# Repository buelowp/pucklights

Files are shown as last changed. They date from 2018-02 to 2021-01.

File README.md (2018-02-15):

# Remote Control Wireless Energizer Puck Lights

There are a new breed of low power LED puck lights available which make use of 433 Mhz radios 
for remote control. However, they currently do not integrate with any sort of Micro allowing 
for more accesible remote control.

This project connects to the provided remote and adds the ability to put a motion detector 
into the system which will turn the lights on or off based on movement and available ambient 
light. The idea is to use the puck lights remotely without having to run power for stair lights 
while achieving a viable benefit.

## What these are
https://www.lowes.com/pd/Energizer-Remote-Controlled-2-Pack-3-in-Battery-Puck-Light/1000268307

## The Plan
Basically, these are battery operated with a 433Mhz receiver, and a 12V remote that has two 
buttons, on and off. By powering the remote with a 12V source, and then regulating the power 
down to 5V for the micro, you can simply run two leads from NPN transistors to the two buttons 
to act as remote triggers. Add in a IR motion detector and a photocell, and you can remotely
trigger the lights on activity. Add in a micro that can easily receive events from the internet
and you can even turn the lights on or off from anywhere.

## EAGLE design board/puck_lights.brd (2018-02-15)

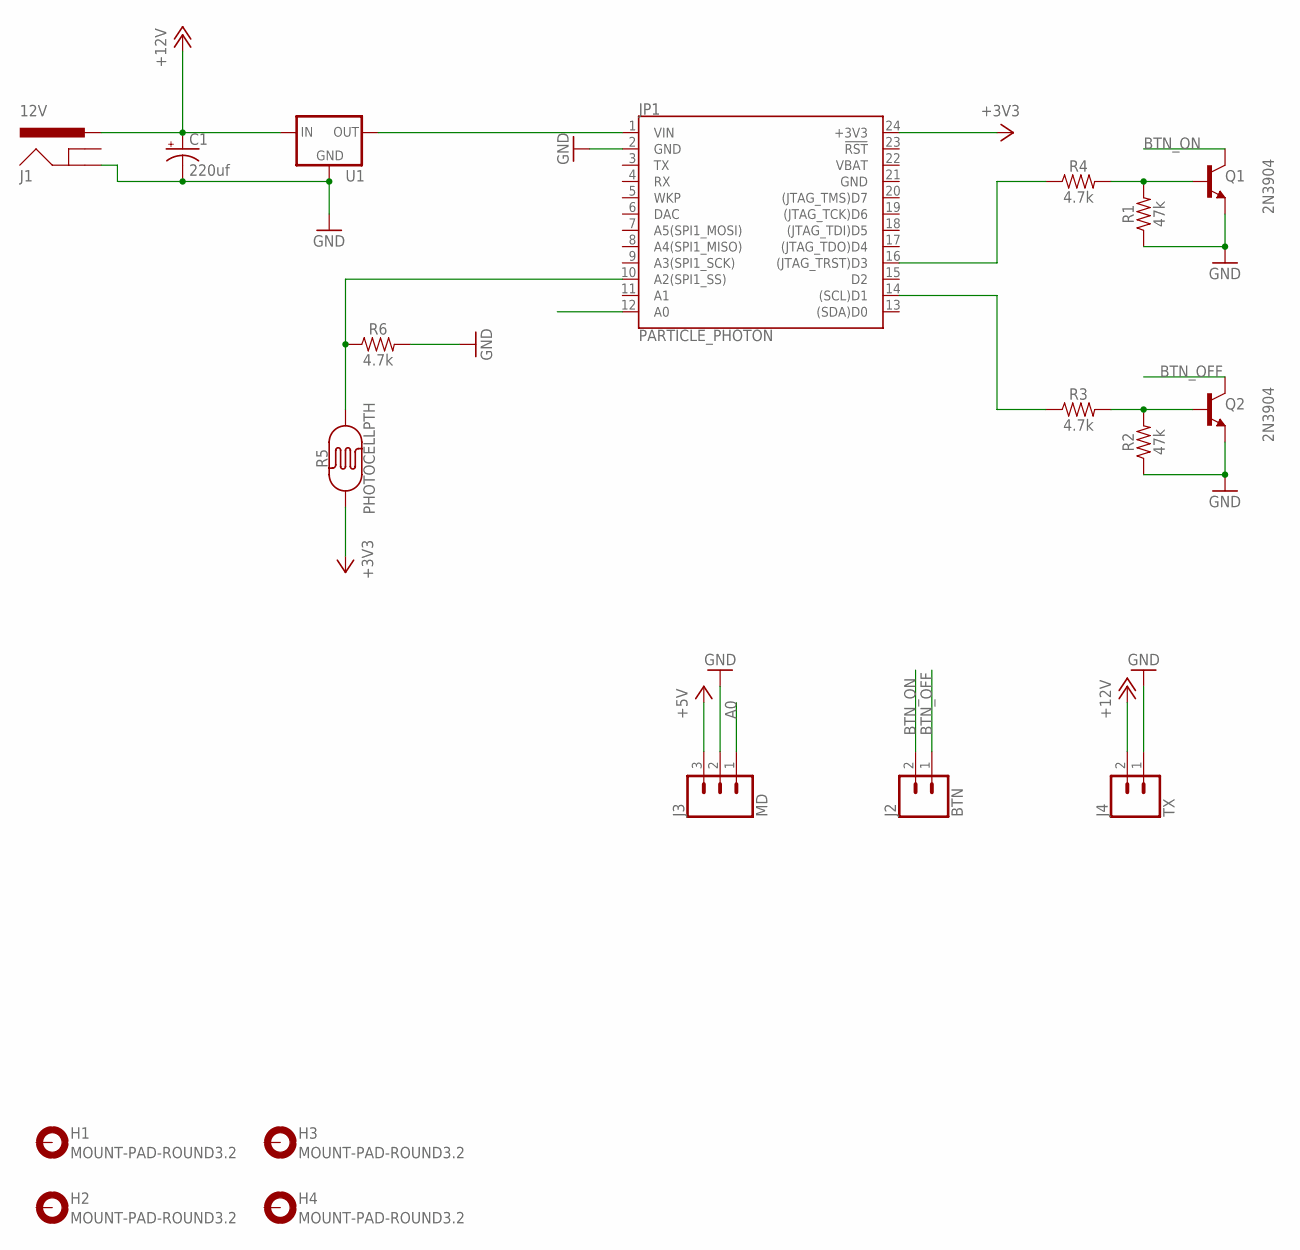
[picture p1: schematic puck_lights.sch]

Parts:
C1: 220uf; CPOL-RADIAL-2.5MM-6.5MM
H1, H2, H3, H4: MOUNT-PAD-ROUND3.2; 3,2-PAD
J1: 12V; POWER_JACK_SMD
J2: BTN; 1X02
J3: MD; JST-3-PTH
J4: TX; 1X02
JP1: PARTICLE_PHOTON
Q1, Q2: 2N3904; TO92
R1, R2: 47k; AXIAL-0.3
R3, R4, R6: 4.7k; AXIAL-0.3
R5: PHOTOCELLPTH; PHOTOCELL
U1: V_REG_78XX-TO-220; TO-220-ALT

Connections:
+3V3: JP1.24 (+3V3), R5.1
+5V: J3.3
+12V: C1.1 (+), J1.VIN0 (PWR), J4.2, U1.IN
A0: J3.1, JP1.12 (A0)
BTN_OFF: J2.1, Q2.1 (C)
BTN_ON: J2.2, Q1.1 (C)
GND: C1.2 (-), J1.P$4 (GND), J3.2, J4.1, JP1.2 (GND), JP1.21 (GND), Q1.3 (E), Q2.3 (E), R1.P$1 (1), R2.P$1 (1), R6.P$2 (2), U1.GND
unnamed: JP1.14 ((SCL)D1), R3.P$1 (1)
unnamed: JP1.1 (VIN), U1.OUT
unnamed: JP1.16 ((JTAG_TRST)D3), R4.P$1 (1)
unnamed: Q2.2 (B), R2.P$2 (2), R3.P$2 (2)
unnamed: Q1.2 (B), R1.P$2 (2), R4.P$2 (2)
unnamed: JP1.10 (A2(SPI1_SS)), R5.2, R6.P$1 (1)
VBAT: JP1.22 (VBAT)

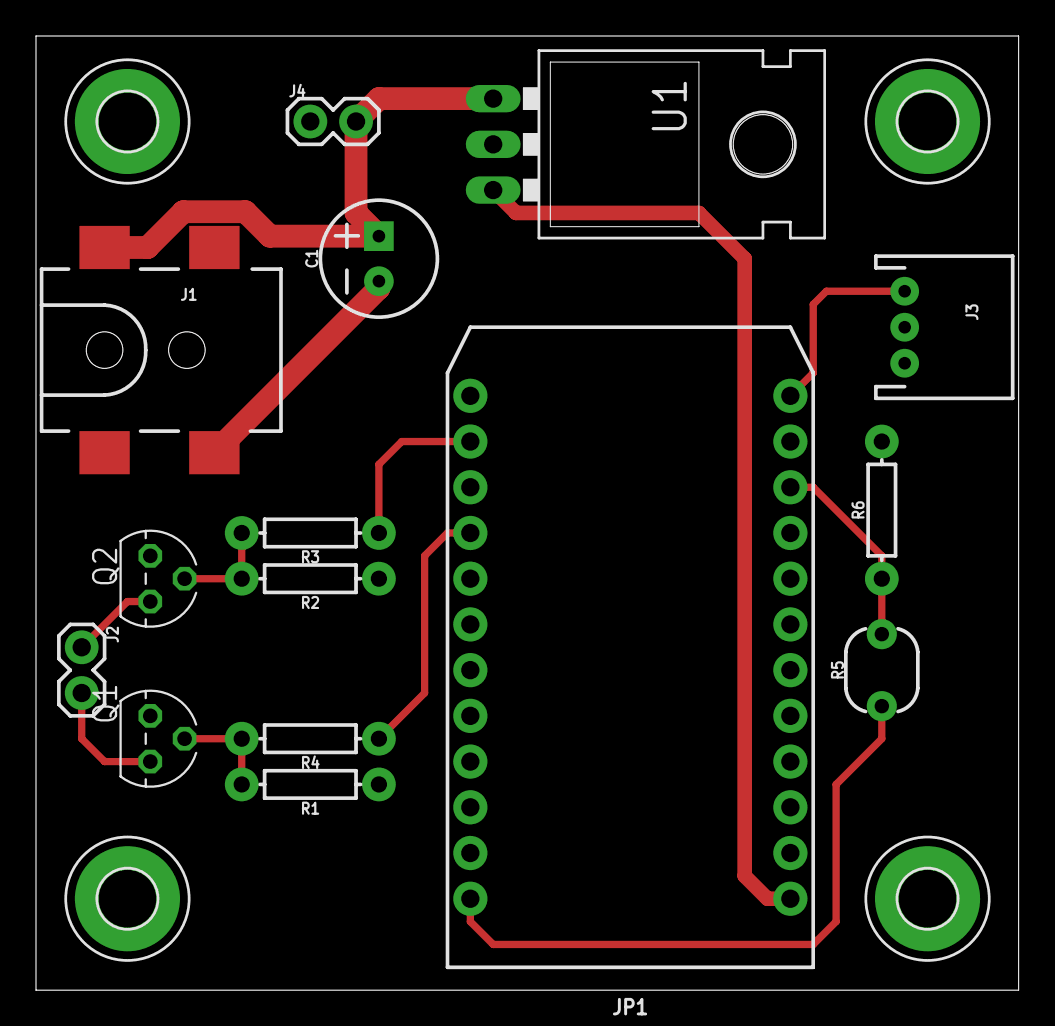
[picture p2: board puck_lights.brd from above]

Board: 2 copper layers, 54.6 x 53.0 mm, 19 parts (0 on the bottom side), 12 nets.

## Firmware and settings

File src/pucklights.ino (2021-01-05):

#include "sunset.h"

#define ON_BUTTON           D1
#define OFF_BUTTON          D5
#define MOTION_DETECT       D2
#define LIGHT_DETECT        A1
#define APP_ID              67
#define DEFAULT_TRIGGER     25
#define ARRAY_SIZE          50

#define ONE_SECOND          (1000)
#define TWENTY_SECONDS      (ONE_SECOND * 20)
#define ONE_MINUTE          (ONE_SECOND * 60)
#define FOUR_MINUTES        (ONE_MINUTE * 4)
#define FIVE_MINUTES        (ONE_MINUTE * 5)
#define ONE_HOUR            (ONE_MINUTE * 60)
#define TWELVE_HOURS        (ONE_HOUR * 12)
#define CST_OFFSET          -6
#define DST_OFFSET          (CST_OFFSET + 1)
#define TIME_BASE_YEAR		2019
#define LATITUDE            42.058102
#define LONGITUDE           -87.984189

const uint8_t _usDSTStart[22] = { 10, 8,14,13,12,10, 9, 8,14,12,11,10, 9,14,13,12,11, 9};
const uint8_t _usDSTEnd[22]   = { 3, 1, 7, 6, 5, 3, 2, 1, 7, 5, 4, 3, 2, 7, 6, 5, 4, 2};

bool g_lightsOn;
bool g_syncDone;
int g_timeZone;
int g_lux;
int g_appid;
int g_trigger;
int g_turnOnLux;
int g_arrayIndex;
int g_average;
int g_highCount;
bool g_motionDetected;
unsigned long g_debounce;
unsigned long g_timeOut;
int g_luxArray[ARRAY_SIZE];
SunSet sun(LATITUDE, LONGITUDE, CST_OFFSET);

int currentTimeZone()
{
    g_timeZone = DST_OFFSET;
    if (Time.month() > 3 && Time.month() < 11) {
        return DST_OFFSET;
    }
    if (Time.month() == 3) {
        if ((Time.day() == _usDSTStart[Time.year() - TIME_BASE_YEAR]) && Time.hour() >= 2)
            return DST_OFFSET;
        if (Time.day() > _usDSTStart[Time.year() - TIME_BASE_YEAR])
            return DST_OFFSET;
    }
    if (Time.month() == 11) {
        if ((Time.day() == _usDSTEnd[Time.year() - TIME_BASE_YEAR]) && Time.hour() <=2)
            return DST_OFFSET;
        if (Time.day() < _usDSTEnd[Time.year() - TIME_BASE_YEAR])
            return DST_OFFSET;
    }
    g_timeZone = CST_OFFSET;
    return CST_OFFSET;
}

void turnLightsOn()
{
    if (!g_lightsOn) {
        digitalWrite(ON_BUTTON, HIGH);
        delay(100);
        digitalWrite(ON_BUTTON, LOW);
        g_lightsOn = true;
    }
    g_timeOut = millis() + FOUR_MINUTES;
}

/*
 * Turn the lights on. This will simply reset the current
 * time off timer each time it observes movement.
 */
int turnLightsOnNet(String)
{
    turnLightsOn();
    return 1;
}

void turnLightsOff()
{
    digitalWrite(OFF_BUTTON, HIGH);
    delay(100);
    digitalWrite(OFF_BUTTON, LOW);
    g_lightsOn = false;
    g_timeOut = 0;
    g_debounce = millis() + TWENTY_SECONDS;
}

/*
 * Turn the lights off
 * This includes resetting the lights are on flag, setting the turn off
 * timer to 0, and starting the lockout timer which keeps stray events
 * from happening as the 433Mh radio tends to activate the motion sensor.
 */
int turnLightsOffNet(String)
{
    turnLightsOff();
    return 0;
}

int setLuxTriggerValue(String lux)
{
    g_trigger = lux.toInt();
    return g_trigger;
}

int averageLux(int lux)
{
    int average = 0;

    if (g_arrayIndex == (ARRAY_SIZE - 1))
        g_arrayIndex = 0;

    g_luxArray[g_arrayIndex++] = lux;
    for (int i = 0; i < ARRAY_SIZE; i++) {
        average += g_luxArray[i];
    }
    g_average = average / ARRAY_SIZE;
    return g_average;
}

void setup()
{
    pinMode(ON_BUTTON, OUTPUT);
    pinMode(OFF_BUTTON, OUTPUT);
    pinMode(MOTION_DETECT, INPUT_PULLDOWN);
    pinMode(LIGHT_DETECT, INPUT);

    digitalWrite(ON_BUTTON, LOW);
    digitalWrite(OFF_BUTTON, LOW);

    g_appid = APP_ID;
    g_trigger = DEFAULT_TRIGGER;
    g_turnOnLux = 0;
    g_arrayIndex = 0;
    g_lightsOn = false;
    g_timeOut = 0;
    g_motionDetected = false;
    g_debounce = 0;
    g_syncDone = true;
    g_highCount = 0;

    Particle.function("On", turnLightsOnNet);
    Particle.function("Off", turnLightsOffNet);
    Particle.function("SetTrigger", setLuxTriggerValue);
    Particle.variable("lux", g_lux);
    Particle.variable("version", g_appid);
    Particle.variable("trigger", g_trigger);
    Particle.variable("state", g_lightsOn);
    Particle.variable("turnonlux", g_turnOnLux);
    Particle.variable("averagelux", g_average);

    Particle.syncTime();

    Time.zone(currentTimeZone());
    sun.setTZOffset(currentTimeZone());

    turnLightsOff();    // Set lights off if we restart
    g_lux = analogRead(LIGHT_DETECT); // Allow us to see the value before we start the loop
}

void loop()
{
    static int lastHour = 25;

    if (millis() < ONE_SECOND) {
        return;         // Delay a bit to let the sensors settle.
    }

    if (Time.hour() != lastHour) {
        Particle.syncTime();
        waitUntil(Particle.syncTimeDone);
        Time.zone(currentTimeZone());
        lastHour = Time.hour();
    }

    g_lux = analogRead(LIGHT_DETECT);
    averageLux(g_lux);

    if (Time.hour() >= sun.calcSunrise() && Time.hour() <= sun.calcSunset())
        return;

    if (g_timeOut >= millis())
        return;

    if (g_lightsOn) {
        turnLightsOff();
        return;
    }

    if (digitalRead(MOTION_DETECT) == HIGH) {
        if (g_debounce >= millis())     // don't turn on within 20 seconds of turning off
            return;
        else
            g_debounce = 0;             // reset so we can turn on now

        /**
         * We need to be both below the trigger, and to have seen
         * 100 straight events. This should avoid false triggers based on one
         * off events from the sensor.
         */
        if ((g_average < g_trigger) && (g_highCount++ >= 100)) {
            g_turnOnLux = g_average;
            g_highCount = 0;
            turnLightsOn();
        }
    }
    else {
        g_motionDetected = false;
        g_highCount = 0;
    }
}

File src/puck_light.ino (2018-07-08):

#define ON_BUTTON           D1
#define OFF_BUTTON          D5
#define MOTION_DETECT       D2
#define LIGHT_DETECT        A1
#define VERSION             53

#define FIVE_MINUTES        (1000 * 60 * 5)
#define TWENTY_SECONDS      (1000 * 20)
#define ONE_MINUTE          (1000 * 60 * 1)

#define DEFAULT_TRIGGER     25

bool g_lightsOn;
unsigned long g_millis;
int g_lux;
int g_luxCloud;
int g_minLux;
int g_version;
bool g_motionDetected;
unsigned long g_timeOut;
unsigned long g_detectRemain;

/*
 * Turn the lights on. This will simply reset the current
 * time off timer each time it observes movement.
 */
int turnLightsOn(String)
{
    if (!g_lightsOn) {
        digitalWrite(ON_BUTTON, HIGH);
        delay(100);
        digitalWrite(ON_BUTTON, LOW);
        g_lightsOn = true;
    }
    g_timeOut = millis() + FIVE_MINUTES;
    return 1;
}

/*
 * Turn the lights off
 * This includes resetting the lights are on flag, setting the turn off
 * timer to 0, and starting the lockout timer which keeps stray events
 * from happening as the 433Mh radio tends to activate the motion sensor.
 */
int turnLightsOff(String)
{
    digitalWrite(OFF_BUTTON, HIGH);
    delay(100);
    digitalWrite(OFF_BUTTON, LOW);
    g_lightsOn = false;
    g_timeOut = 0;
    g_detectRemain = millis() + TWENTY_SECONDS;
    return 0;
}

int setLuxValue(String lux)
{

}

void setup()
{
    pinMode(ON_BUTTON, OUTPUT);
    pinMode(OFF_BUTTON, OUTPUT);
    pinMode(MOTION_DETECT, INPUT_PULLDOWN);
    pinMode(LIGHT_DETECT, INPUT);

    digitalWrite(ON_BUTTON, LOW);
    digitalWrite(OFF_BUTTON, LOW);

    Particle.function("On", turnLightsOn);
    Particle.function("Off", turnLightsOff);
    Particle.function("SetLux", setLuxValue);
    Particle.variable("lux", g_lux);
    Particle.variable("min", g_minLux);
    Particle.variable("version", g_version);

    g_lightsOn = false;
    g_timeOut = 0;
    g_motionDetected = false;
    g_millis = millis();
    g_detectRemain = 0;
    g_version = VERSION;
    g_luxCloud = 0;
    g_minLux = 5000;

    turnLightsOff(String());
    g_lux = analogRead(LIGHT_DETECT);
}

void loop()
{
    int trigger = DEFAULT_TRIGGER;
    g_lux = analogRead(LIGHT_DETECT);
    if (g_minLux >= g_lux)
        g_minLux = g_lux;

    if (g_luxCloud != 0) {
        trigger = g_luxCloud;
    }
    g_millis = millis();
    // Give the PIR about a minute to settle down to avoid
    // false positives.
    if (g_millis < ONE_MINUTE)
        return;

    if (g_detectRemain < millis()) {
        g_detectRemain = 0;
    }

    if (g_timeOut < millis() && g_lightsOn) {
        turnLightsOff(String());
        return;
    }

    if (digitalRead(MOTION_DETECT) == HIGH) {
        g_motionDetected = true;
        if ((g_lux < trigger) && (g_detectRemain == 0)) {
            turnLightsOn(String());
        }
    }
    else {
        g_motionDetected = false;
    }
}

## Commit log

2018-02-15 Adding content
    [puck_lights.brd, puck_lights.sch]
2018-02-15 Adding remote functions to turn light on or off Fixing a few bugs
    [puck_light.ino]
2018-02-15 Fixing a bug in how we read the photocell
    [puck_light.ino]
2018-02-19 First working version
    * Adds a lockout to avoid instant retriggering
    * Adds a 1 minute warmup for the PIR
    * Sets light timeout to 5 minutes
    [puck_light.ino]
2018-05-12 Fixing up and installing
    * Fixed light sense value to be better for the actual hallway.
    [puck_light.ino]
2018-07-08 Some fixes
    Added function to set trigger value directly
    Dropped default to 25
    Made it possible to see last min value since reboot
    [puck_light.ino]
2019-12-21 Updates
    * Fixed it to not turn on during the day
    * Added Time support for that function
    * Shorted the time on period to 4 minutes
    [pucklights.ino]
2021-01-04 fixes for issues with randomly turning on
    [pucklights.ino]
2021-01-05 Fixups
    * Set lockout times to be sunrise/sunset, not a fixed time
    * Move some setup code around, and remove the 1 minute delay for a 1 second delay
    [pucklights.ino]

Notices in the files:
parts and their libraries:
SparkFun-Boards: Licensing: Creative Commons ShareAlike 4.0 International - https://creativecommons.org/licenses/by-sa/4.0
